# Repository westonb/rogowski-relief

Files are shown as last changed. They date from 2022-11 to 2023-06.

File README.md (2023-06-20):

# rogowski-relief
## An open source rogowski coil based current probe

This project is a rogowski coil based current probe designed to measure high frequency AC currents in tight spaces.
The sensing coil is optimized to be small enough to fit between the leads of a TO-220 transistor and can be slipped around the leads of many through hole power components for non-intrusive current measurements. 
The project consists of the rogowski coil and the integrator/amplifier which conditions the signal from the rogowski coil and provides an output voltage proportional to the current flowing in a conductor encircled by the rogowski coil. 

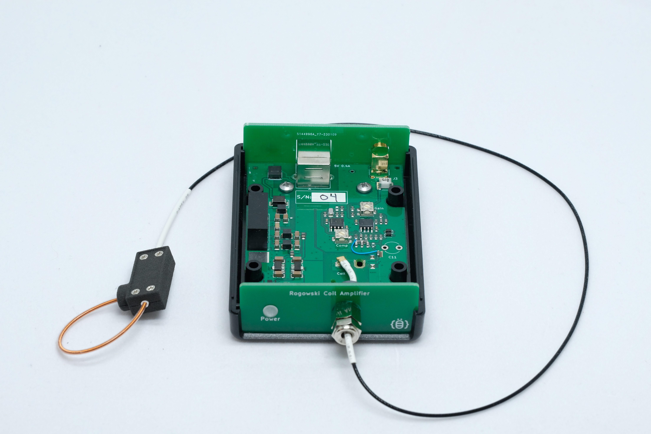
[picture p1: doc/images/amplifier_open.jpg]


## Operation
The sensing coil is open ended, with the free end held in place by a captive O-ring.
The enables the coil to be placed around a wire without breaking the circuit.
The amplifier provides a 0.1V/A output through a SMA connector and is designed to drive a 1M oscilloscope input through a coaxial cable. 
The amplifier is powered through a USB-B connector and draws less than 2W. 

## Specifications 

### Typical Electrical Performance

- **Bandwidth**: 800 Hz - 25 MHz
- **Sensitivity**: 0.1 Volts/Amp
- **Max Current**: +/- 30 A
- **Noise**: 6 mA RMS
- **Slew Rate**: 1 A/ns 

### Coil
- **OD**: < 1.7mm
- **Length**: 70mm

## Project Status
The current probe meets the original design goals and is suitable for general purpose lab use.
The most recently fabricated version of the integrator had some issues with interference from wireless signals (WiFi and LTE).
The PCB files in the latest commit have layout changes to fit the circuitry under a metal shielding can, which should largely remedy the issue.
There are only minor electrical revisions in the updated version, but it remains untested.

## Project Files

LTSpice simulation files for the time domain and frequency domain as well as noise simulation of the system are in the [sim](sim/) directory.
PCB design files and schematics are in the [PCB](pcb/) directory.
STL files of for the rogowski coil, mechanical BOM, and build instructions are in the [mech](mech/) directory.
Schematic of the integrator provided below for convenience. 

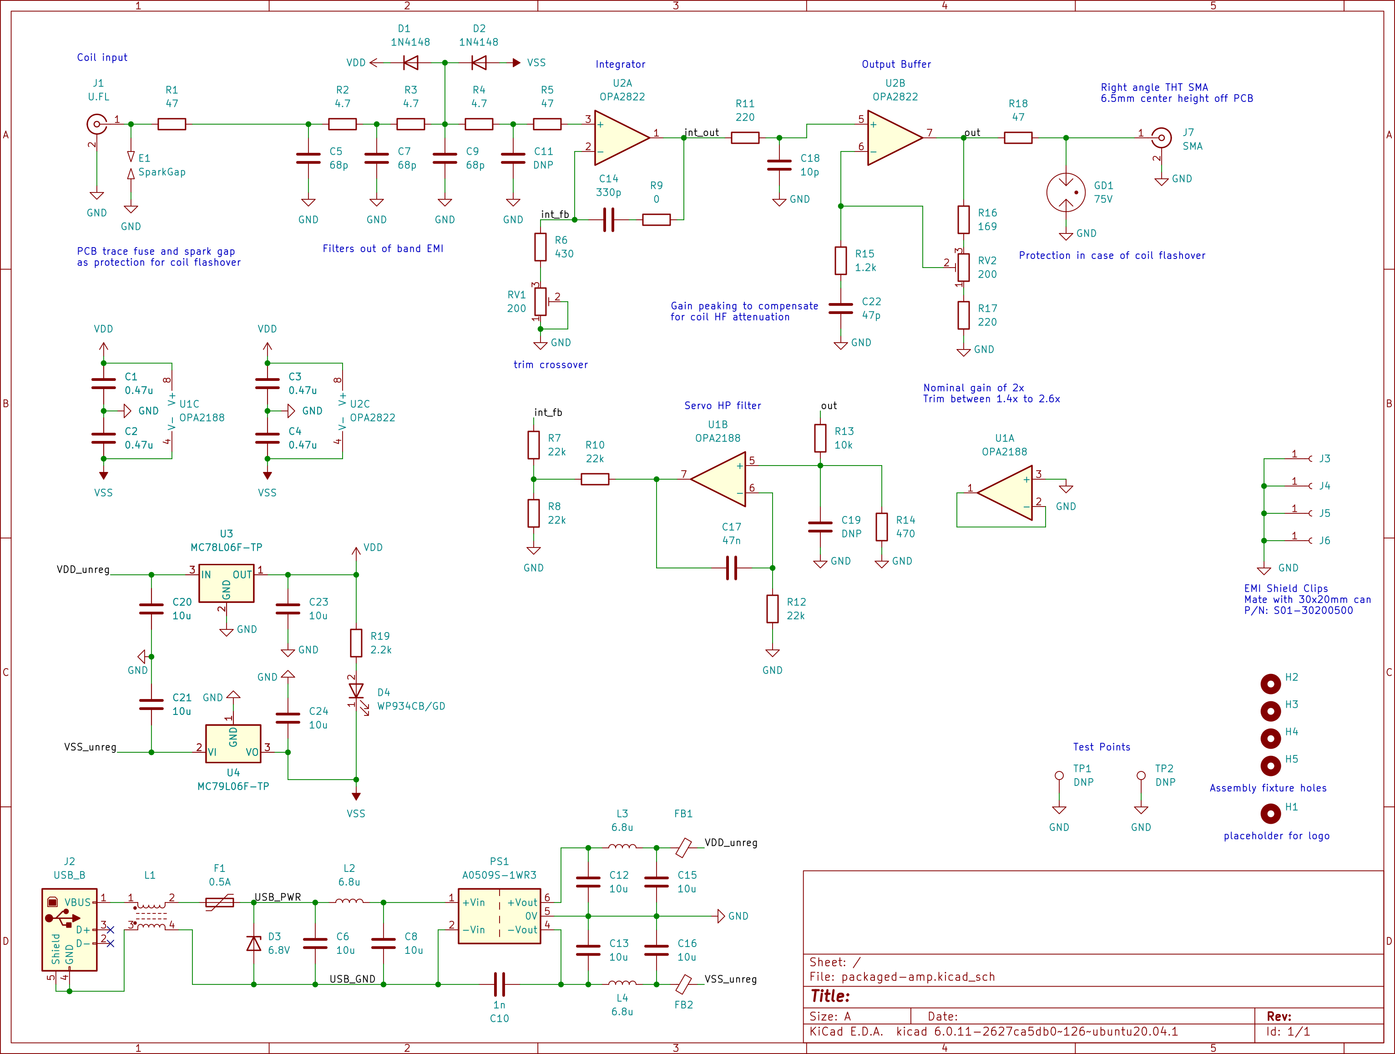
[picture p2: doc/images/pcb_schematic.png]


## Operating Principles 

### Rogowski Coil

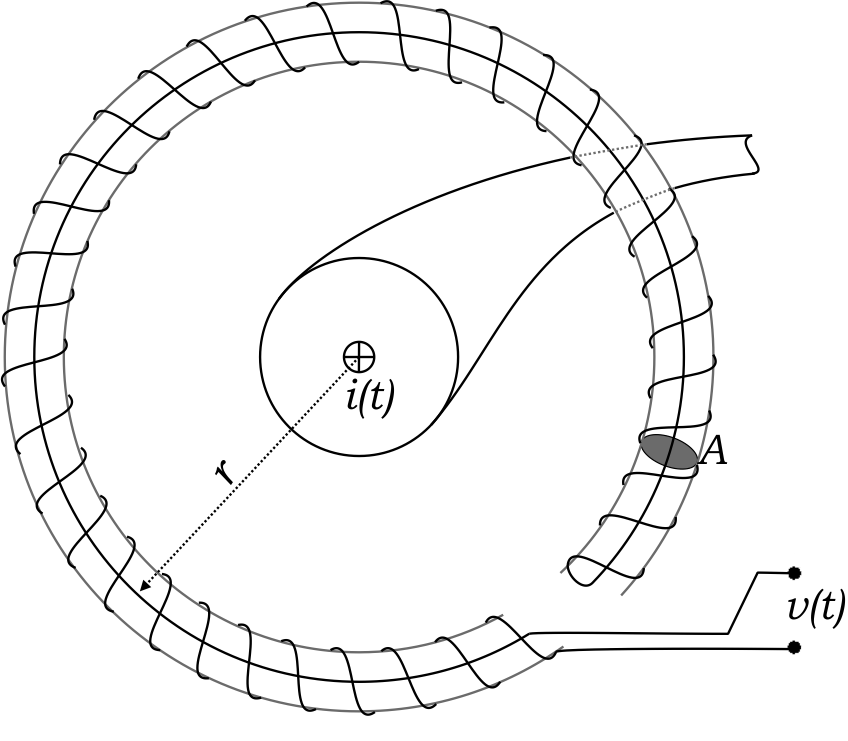
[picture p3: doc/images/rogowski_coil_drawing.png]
|  | 
|:--:| 
| *Rogowski Coil Drawing. Source: [Wikipedia](https://en.wikipedia.org/wiki/File:Rogowski_coil.png)* |

A rogowski coil is a toroidally wound air coil, consisting of many turns of wire wrapped around a coil form, with the start and end of the coil form joined together.
Each turn of the coil generates a voltage proportional to the change in the coupled magnetic field.
The sum of the voltage produced by all the turns is proportional to the change in the line integral of magnetic field around the path of the coil. 
As expressed by Ampere's law, the line integral of the magnetic field for any closed path is proportional to the current flowing in the enclosed area. 
Thus, the rogowski coil produces a voltage proportional to the change in current in a wire encircled by the coil with the output signal independent of the positioning of the wire. 
This allows for a flexible air-cored current sensor.
Unlike a current transformer, the rogowski coil generates a voltage proportional to the dI/dt and the signal must be integrated to produce an output proportional to current.
Additionally, as the dI/dt of a DC current is zero, the rogowski coil can not measure a DC current. 

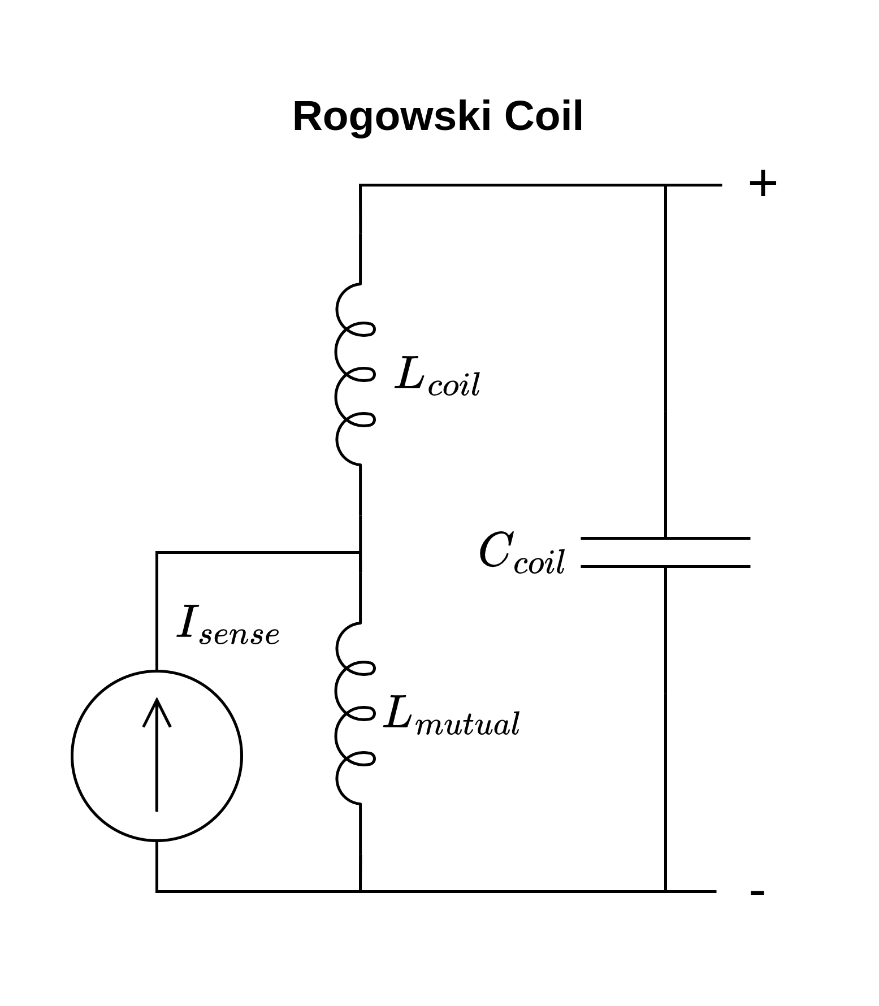
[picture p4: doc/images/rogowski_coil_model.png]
|  | 
|:--:| 
| *Circuit Model of Rogowski Coil* |

The rogowski coil can be modeled as a mutual inductance representing the flux coupling between the encircled wire and the coil, and the physical inductance and capacitance of the coil.
The induced signal can be modeled as a current source equal to that of the current in the encircled wire that is parallel with the mutual inductance.
The inductance and capacitance of the coil limit the maximum bandwidth and are dependent on the geometry of the coil.
The winding diameter and pitch determine the characteristic impedance of the coil, which determines the ratio of inductance to capacitance.
The bandwidth of the rogowski coil is maximized when the coil is terminated with a resistance equal to the characteristic impedance.
The total values of inductance and capacitance are determined by the length of the coil, which is proportional to the number of turns.

### Integrator
This project uses an op-amp based integrator to process the signal from the rogowski coil.
As integrator gain increases at low frequencies, the noise of the integrator ultimately limits the achievable low frequency bandwidth and is one of the most important design criteria.

This design uses an non-inverting integrator, best described in the paper [High Performance Rogowski Current Transducers](https://gmw.com/wp-content/uploads/2019/01/ias_2000_pem.pdf), and a servo high-pass filter with a second op-amp, best described in [A new filter topology for analog high-pass filters](https://www.ti.com/lit/an/slyt299/slyt299.pdf) to roll off the low frequency gain.

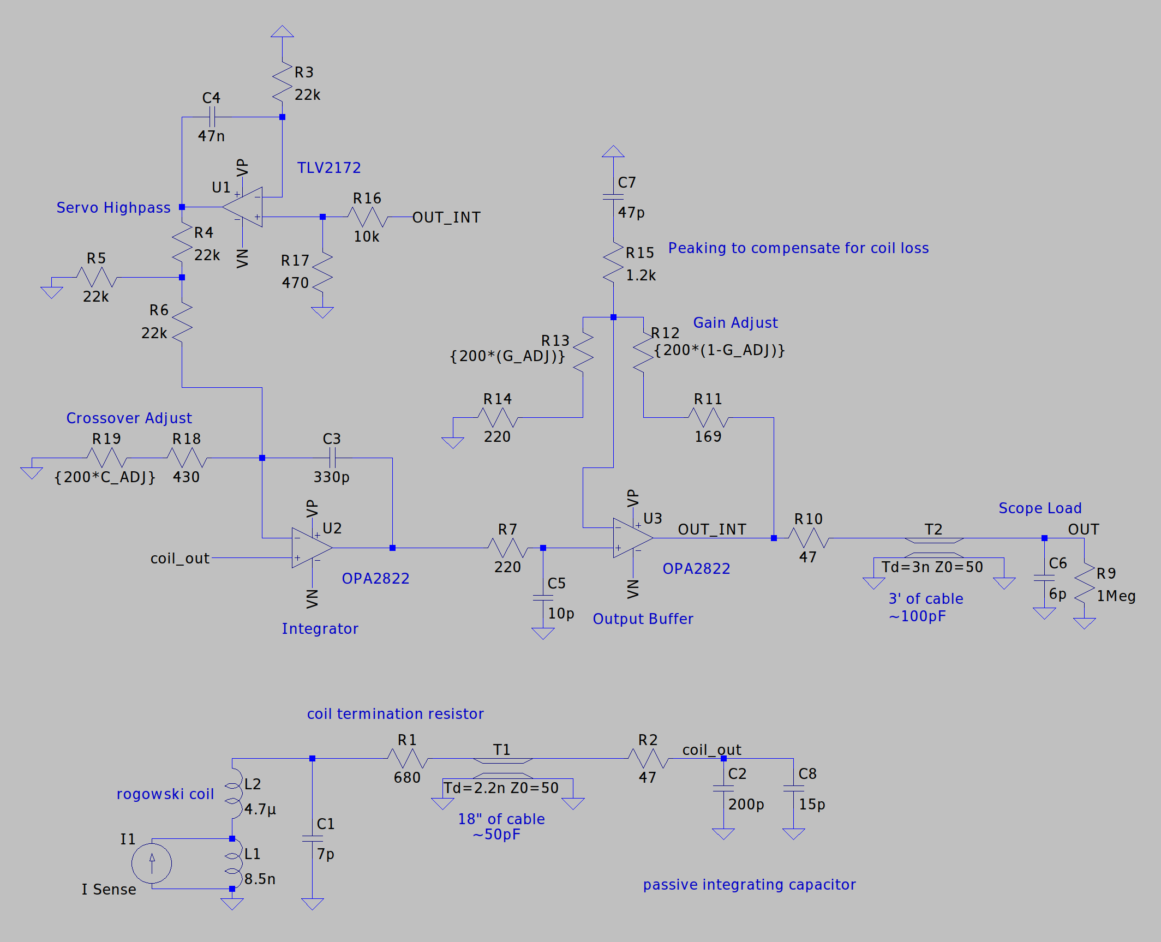
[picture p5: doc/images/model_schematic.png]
|  | 
|:--:| 
| *Annotated schematic of Rogowski coil and integrator* |

The non-inverting integrator consists of a passive RC integrator for high frequency integration and an op-amp integrator for low frequencies.
The passive RC integrator is comprised of the termination resistor for the rogowski coil, which matches the characteristic impedance of the rogowski coil and is co-located with the rogowski coil.
This allows for the capacitance of the cable between the rogowski coil and the integrator, which would otherwise limit bandwidth, to be incorporated as part of the integrator capacitance.
The non-inverting integrator requires that the crossover frequencies of the passive RC integrator and the op-amp match, necessitating a trimmer resistor.

The servo high-pass filter reduces the gain of the integrator below the cutoff frequency instead of leveling off the gain.
This reduces the noise of the system and nulls the DC offset of the amplifier, which could otherwise limit the output signal range.

An additional op-amp is used as an output buffer to provide adjustable gain to normalize the output to a fixed V/A ratio, and provide high frequency peaking to compensate for losses in the rogowski coil.

The op-amp used for the integrator was chosen for its low noise and high bandwidth.
Changing the op-amp can drastically change the output noise.

### Power Supply
The integrator is powered through a USB-B connector.
An isolated DC/DC converter module is uses to provide bipolar outputs of +/-9V which is then regulated down to +/-6V with linear regulators.
The linear regulators reduce switching noise which could otherwise couple into the output.
The isolated DC/DC converters are a commodity component that provide a bipolar output with lower cost and complexity than could be achieved with a solution using discrete components.
Additionally, the isolated module prevents any return current from passing through the output cable, which can inject noise or cause a DC offset.

## Safety 
No safety guarantees or warranty is implied for this design.
However, some safety precautions were taken as the rogowski coil could come into contact with conductors that are at a high voltage.
A PCB trace fuse on both connections from the coil is included on the PCB layout in the hope that the traces will blow and isolate the coil if the coil arcs over.
Additionally, a gas discharge tube is included on the output to further protect a connected device if such an arc-over would occur.

No voltage rating of the rogowski coil is implied or tested
The recommended heat-shrink has a wall thickness of 8 mil and a dielectric strength of 2kV/mil.
The recommended magnetic wire is MW 35-C rated and as such has a minimum dielectric strength of 2340V.
Mechanical wear and high dv/dt signals both adversely impact the voltage rating.

## Demo
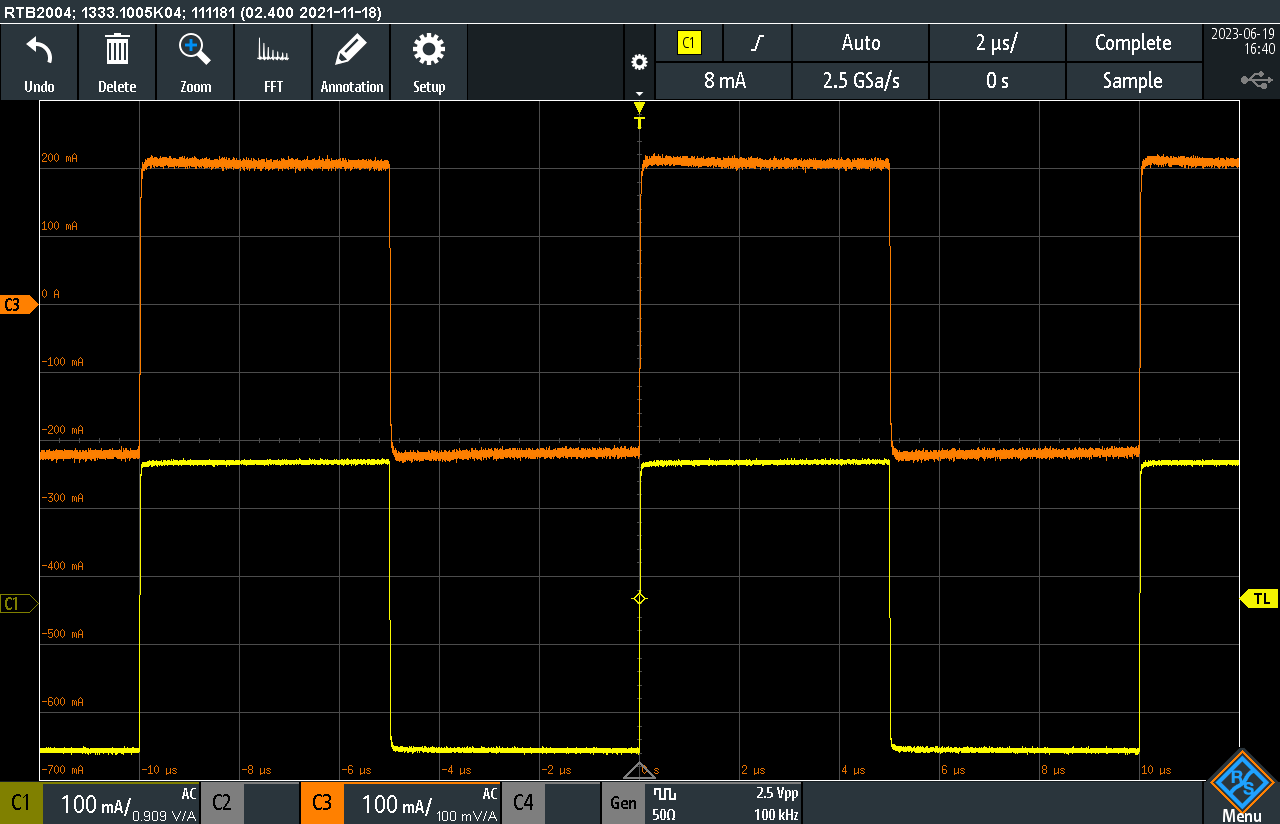
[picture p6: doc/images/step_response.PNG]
|  | 
|:--:| 
| *Probe step response. Reference (yellow) and probe output (orange)* |

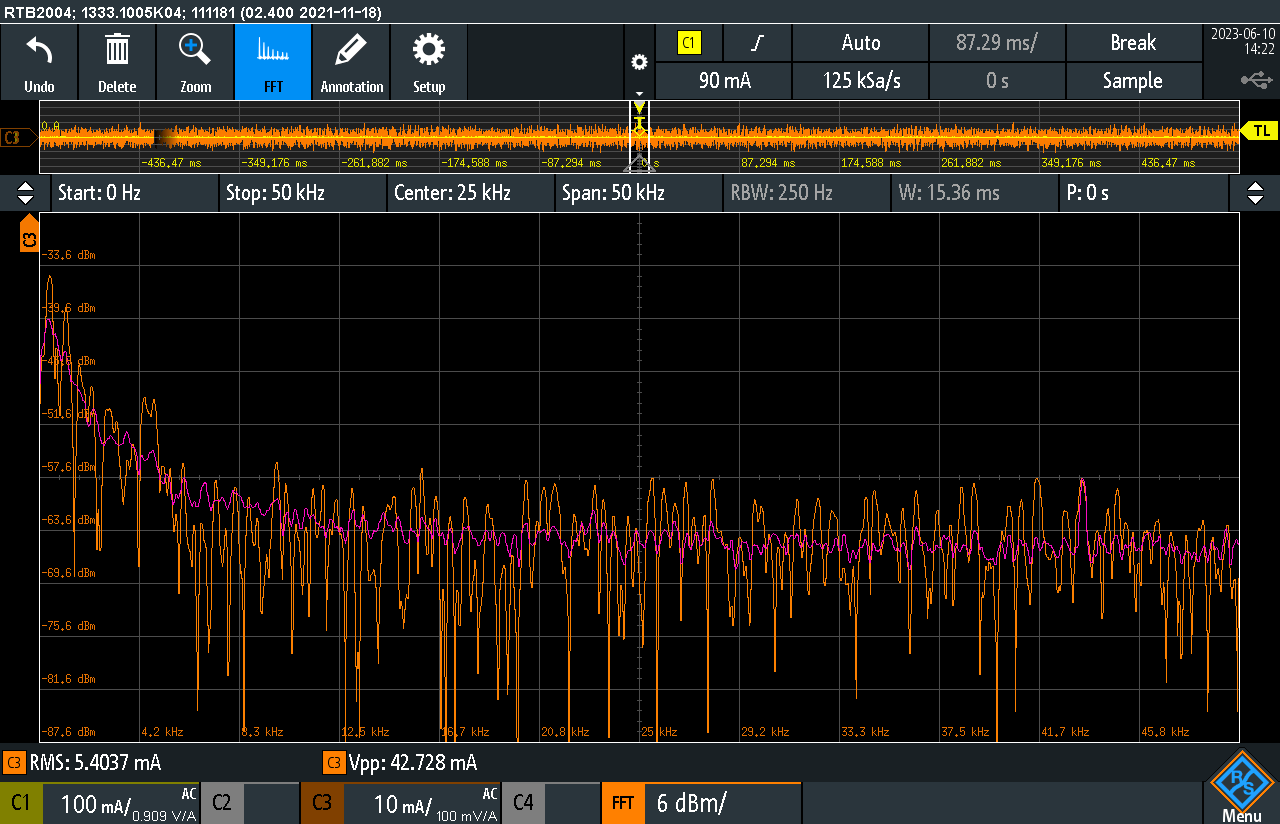
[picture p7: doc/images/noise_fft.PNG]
|  | 
|:--:| 
| *Output Noise and FFT* |

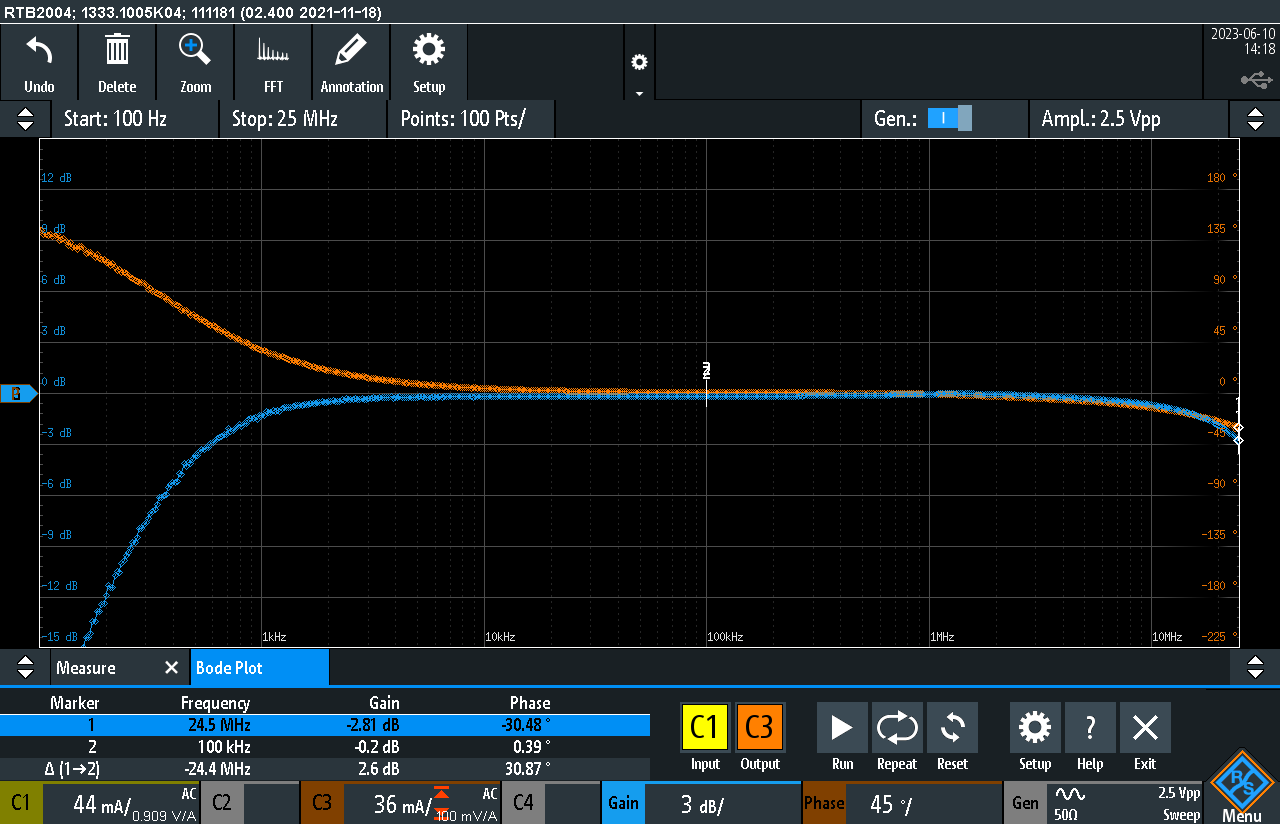
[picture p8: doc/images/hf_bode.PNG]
|  | 
|:--:| 
| *Probe frequency response* |

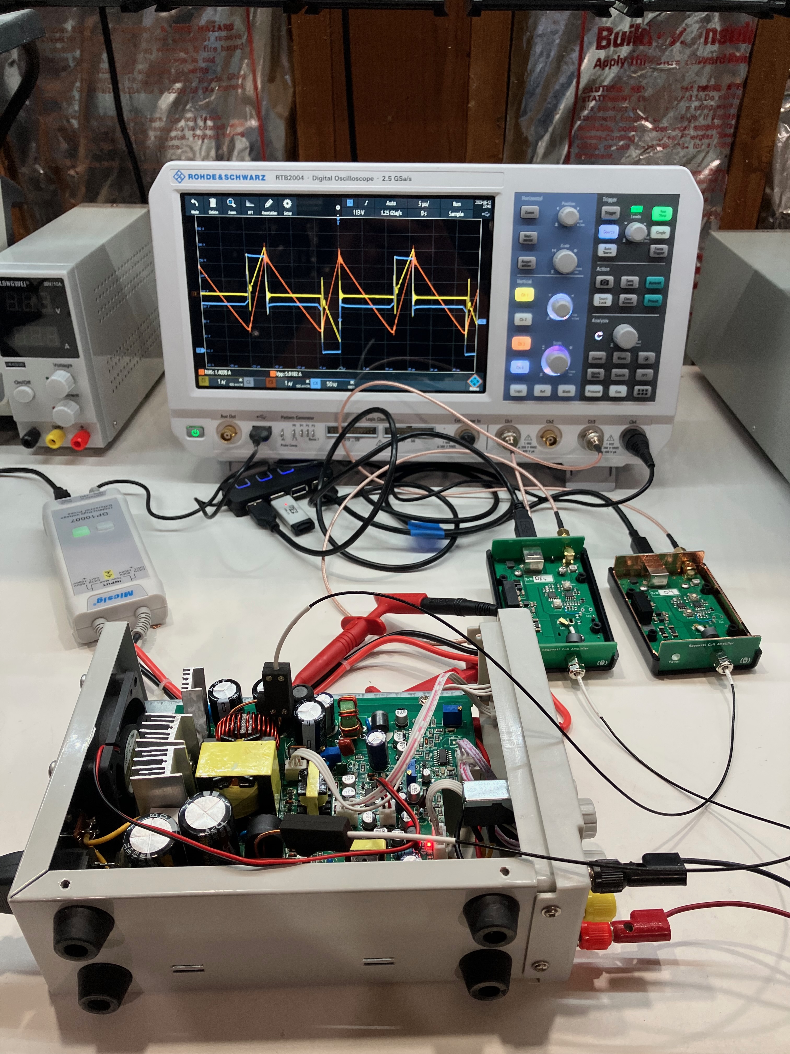
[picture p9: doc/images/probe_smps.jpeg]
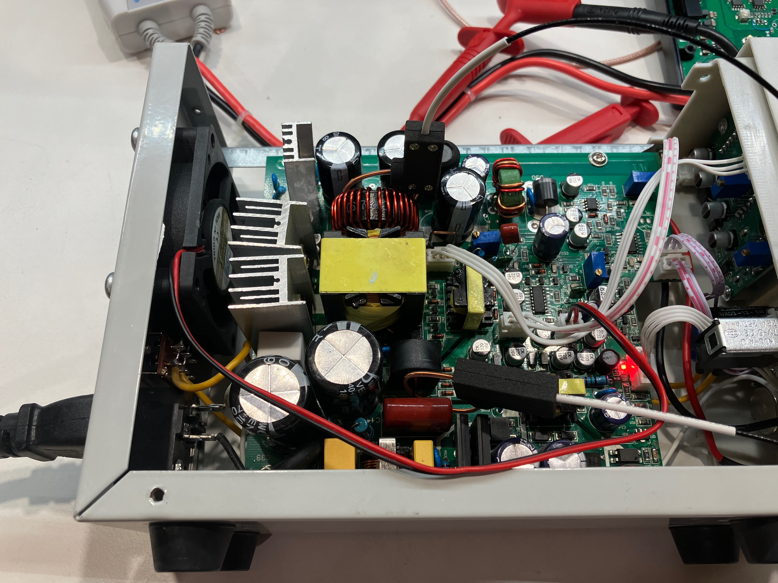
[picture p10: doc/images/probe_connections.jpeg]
|   | 
|:--:| 
| *Probing primary current (yellow) and output choke current (orange) of a SMPS* |

## Open Source
This work is licensed under a
[Creative Commons Attribution-ShareAlike 4.0 International License][cc-by-sa].

[][cc-by-sa]

[cc-by-sa]: http://creativecommons.org/licenses/by-sa/4.0/
[cc-by-sa-image]: https://licensebuttons.net/l/by-sa/4.0/88x31.png
[cc-by-sa-shield]: https://img.shields.io/badge/License-CC%20BY--SA%204.0-lightgrey.svg

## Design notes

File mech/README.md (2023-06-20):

# Build Instructions

## Rogowski Coil
The rogowski coil assembly consists of the wound coil, the 3D printed housing, and a small PCB which connects the rogowski coil to a U.FL connector and holds the termination resistor.

This rogowski coil design involved winding countless coils and trying over 20 types of heatshrink to find a design with good electrical performance, an outer diameter less than 1.7mm so the coil can fit between the leads of a TO-220 package, and is mechanically robust to bending and abrasion.
The integrator design is tuned to the properties of the rogowski coil described here.
If the coil size is changed or different materials are used the coil sensitivity will be different and the integrator may not be able to be adjusted for a nominal gain of 0.1V/A or a flat pulse response.

When winding the coil it is of utmost importance that the winding are uniform with no gaps or overlaps.
A constant winding tension is important as the tension causes shrinkage of the PTFE tube and a non-uniform cross section degrades the rejection of external magnetic fields.

As a general summary of the coil winding and assembly, the coil is wound on a PTFE tube.
The starting wire is secured by a small hole in the tube and passed through the center of the tube such that the start and end wires are at the same end.
UV cure epoxy is used to temporally secure the coil end after winding and the coil is protected with FEP heatshrink.
Additional heat shrink is used to strain relief the coil and and the coaxial cable that connects the rogowski coil to the integrator.

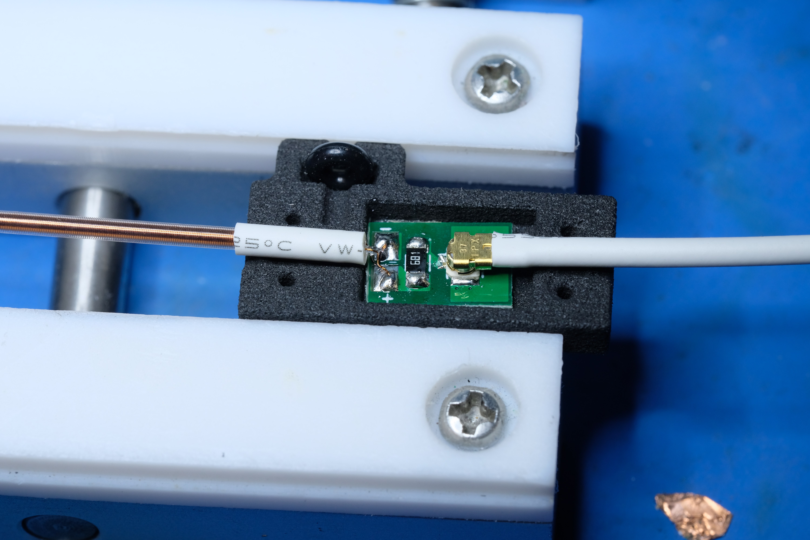
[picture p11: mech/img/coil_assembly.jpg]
|  | 
|:--:| 
| *Rogowski coil assembly before top case is installed* |

### 3D prints
1x of `coil_retainer_bottom.stl` and `coil_retainer_top.stl`
Printed in SLS nylon.
Test parts were printed out of 3201PA-F Nylon through JLCPCB.

### PCB
Coil terminator board populated with 680 ohm 1206 resistor and U.FL connector

### Parts
* 1.3x shrink ratio FEP for 18 Wire Gage, McMaster-Carr P/N 8703K114
* 2.5mm diameter 2x shrink ratio Polyolefin heat shrink, Digikey P/N HST-04-WT-4
* 0.6mm ID x 1mm OD PTFE tubing, [Amazon](https://www.amazon.com/gp/product/B07F5X51F5/)
* 36AWG MW 35-C magnet wire, Remington Industries P/N 36S200P
* 450mm 1.37mm coax cable, U.FL to U.FL, Digikey P/N 732-636201100450-ND
* 4x M1.6x6 flat head self tapping screw McMaster-Carr P/N 95893A162
* double sided adhesive tape, 3M 9495LE or similar
* UV cure epoxy, Loctite 3494 or similar
* 1/16"-004 O-Ring, McMaster-Carr P/N 9452K12

### Build Instructions

#### Bare Coil
1. Cut 1mm OD PTFE tube to 90mm length, cut hole big enough to pass 36 AWG wire 2mm from one end.
2. Thread 36 AWG magnet wire through the hole and have the wire exit the opposite end of the PFTE tube.
3. With the end of the magnet wire secured, wind a coil around the tube, winding should extend to the bottom 4mm of the tube. Use constant tension and ensure there are no gaps, overlaps, or kinks. This process can be easier by using a think stainless steel wire as a mandrel to hold the tube.
4. Secure the end of the winding with a small dab of UV cure epoxy. Cut the coil ends to 5mm length
5. Cut 100mm of the FEP heatshrink and heatshrink the coil with hot air at 250C. Start from the coil end and ensure the heat shrink starts flush with the PFET tube. After heating, trim the heatshink to be flush with the far end of the PTFE tube.
6. Cut 10mm of the Polyolefin heat shrink and apply to the wire end of the coil. Make sure that the heat shrink is flush with the existing heatshrink and coil end, it should not overhang. Process with 250C hot air. 
7. Strip the last 2mm of the wires of enamel and tin with solder.

#### Coil Assembly
1. Cut 50mm of the Polyolefin heat shrink and apply to both ends of the coax cable. The heat shrink should be flush with the neck of the U.FL connector. Process with 250C hot air.
2. Secure the coil terminator PCB to the inside of the bottom coil retainer housing with adhesive tape. The board edge should be flush with the wall where the rogowski coil is connected.
3. Solder the rogowski coil leads to the pads on the coil terminator board. Minimize any exposed loops. 
4. Connect the coaxial cable to the U.FL connector on the coil terminator board.
5. Place an O-ring in the O-ring retaining grove.
6. Make sure that the end of the rogowski coil is flush with the inner wall. Cover with the top coil retainer housing, compress the housing halves together and secure with M1.6x6 self tapping screws. Use gentle tightening force to ensure screw holes do not strip out. 

## Integrator 
The final assembly is the integrator PCBA and the rogowski coil.
The project is contained in an off the shelf project box and uses PCB based front and rear panels.
The integrator PCBA was optimized for assembly with the JLCPCB PCBA service, but component availability varies.
The KiCad project contains both a BOM with LCSC part numbers and a BOM with western part numbers stocked at Digikey. 

|  | 
|:--:| 
| *Complete current probe with top case open* |

### PCBs
* Integrator PCBA
* Front panel PCB
* Rear Panel PCB

### Parts

* \#4-1/4" thread cutting screws, McMaster-Carr P/N 94629A150
* M6X1.0 Cable gland, Generic, [Aliexpress example](https://www.aliexpress.us/item/3256803804996455.html)
* M6X1.0 thin hex nut, McMaster-Carr P/N 90710A038
* ABS Project Enclosure, Digikey P/N 377-1651-ND
* Ferrite EMI suppression bead, Digikey P/N 1934-1323-ND
* 5mm LED light pipe, Digikey P/N 492-1531-ND

#### Assembly
1. Attach the M6 cable gland to the front panel PCB with the M6 nut and tighten. Press fit the LED light pipe into the front panel.
2. Slide the rear panel over the SMA and USB connectors of the integrator PCB and slide the integrator PCBA and panel PCBs into the project box.
3. Secure integrator PCBA to the project box with the \#4-1/4" screws.
4. Thread the coaxial cable of the rogowski coil assembly through the cable gland. 
5. Slide the ferrite bead over the side of the coaxial cable that is inside the project box.
6. Connect the U.FL connector of the rogowski coil assembly to the U.FL connector of the integrator PCBA. Adjust the cable length such that the cable is not under tension and then tighten the cable gland.
7. Secure the ferrite bead to the integrator PCBA with adhesive or zip-tie. 
8. After calibration, install the top of the project box. 

#### Calibration
With a 100KHz square wave current source adjust the gain and compensation trimmer resistors such that the pulse response is flat and the probe gain is the nominal 0.1V/A.
The compensation trimmer adjusts the rising edge of the waveform and also impacts the gain and should be adjusted first.

A function generator driving a 10 turn coil and a 1 ohm shunt resistor to provide a reference signal should provide a sufficient signal for calibration.
When multiple loops of the same wire pass through the sensing coil the measured current is the current flowing through the wire times the number of turns.

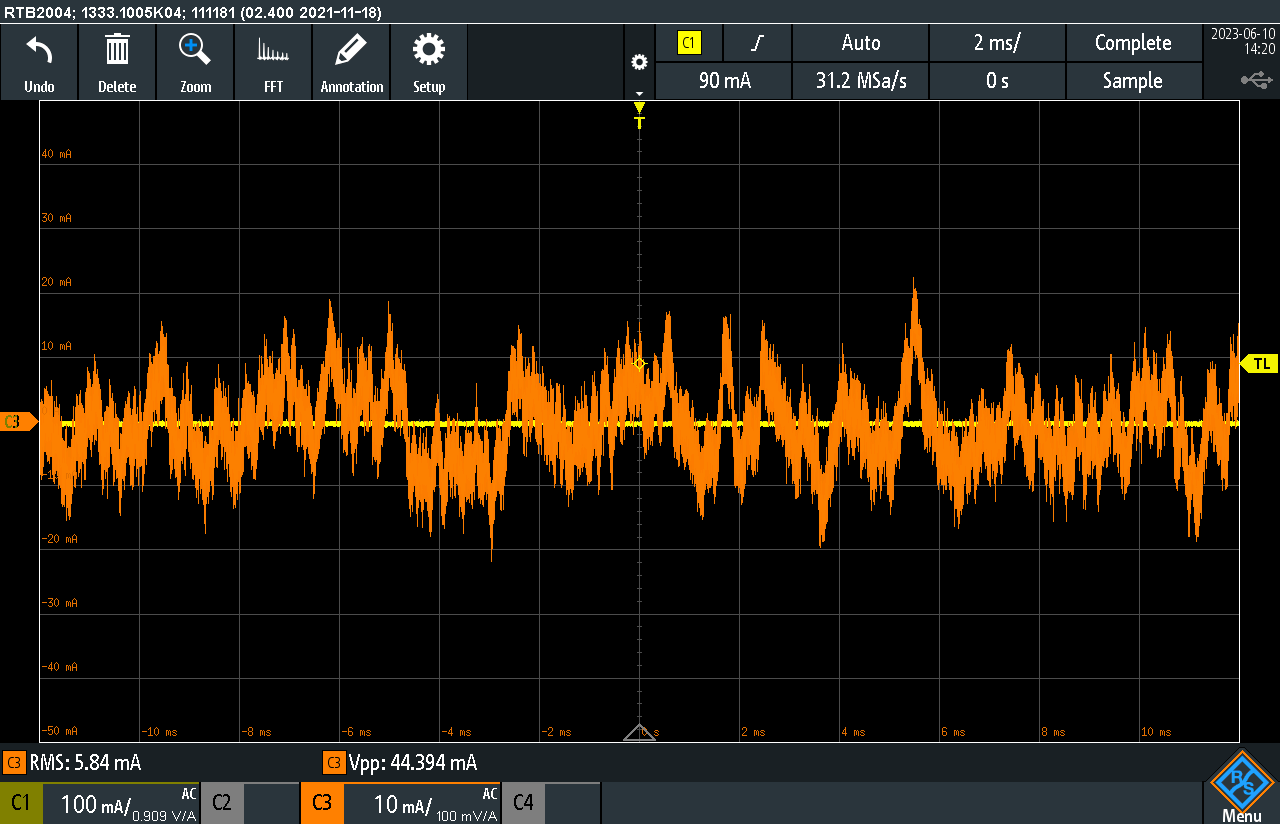
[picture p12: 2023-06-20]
doc/images/noise.PNG

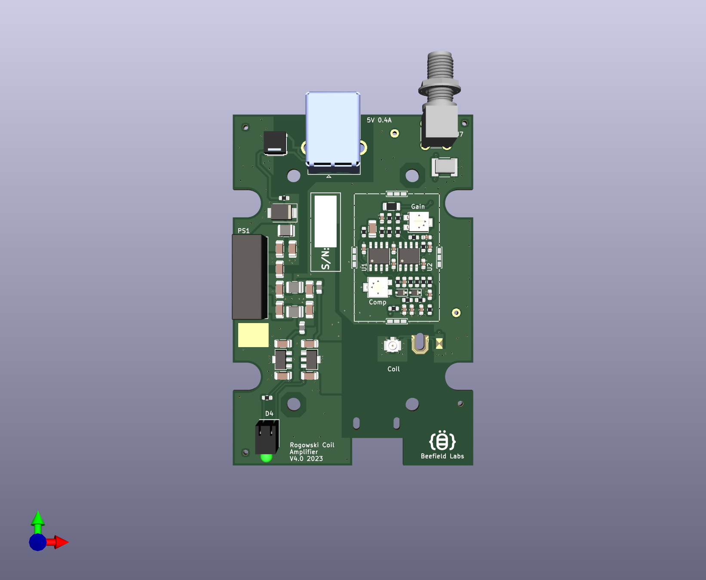
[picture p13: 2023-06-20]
doc/images/pcb_render.png

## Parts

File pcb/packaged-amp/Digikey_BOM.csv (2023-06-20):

Ref | Qty | Value | Footprint | Description | MPN
C1, C2, C3, C4, | 4 | 0.47u | Capacitor_SMD:C_0603_1608Metric | Unpolarized capacitor | CL10B474KA8NNNC
C5, C7, C9, | 3 | 68p | Capacitor_SMD:C_0603_1608Metric | Unpolarized capacitor | CL10C680JB8NNNC
C6, C8, C12, C13, C15, C16, C20, C21, C23, C24, | 10 | 10u | Capacitor_SMD:C_1206_3216Metric | Unpolarized capacitor | CL31A106KBHNNNE
C10, | 1 | 1n | Capacitor_SMD:C_1206_3216Metric | Unpolarized capacitor | 1206B102K202NT
C11, C19, | 2 | DNP | Capacitor_SMD:C_0603_1608Metric | Unpolarized capacitor
C14, | 1 | 330p | Capacitor_SMD:C_0603_1608Metric | Unpolarized capacitor | CL10C331JB8NNNC
C17, | 1 | 47n | Capacitor_SMD:C_1206_3216Metric | Unpolarized capacitor | GRM31M5C1H473JA01L
C18, | 1 | 10p | Capacitor_SMD:C_0603_1608Metric | Unpolarized capacitor | CL10C100JB8NNNC
C22, | 1 | 47p | Capacitor_SMD:C_0603_1608Metric | Unpolarized capacitor | CL10C470JB8NNNC
D1, D2, | 2 | 1N4148 | Diode_SMD:D_SOD-323F | Diode | 1N4148WS RRG
D3, | 1 | 6.8V | Diode_SMD:D_SMB | Zener diode | P6SMB6.8CA/TR13
D4, | 1 | WP934CB/GD | wbraun_smd:LED-T1-RIGHT-ANGLE_4.6x4.4mm | Light emitting diode | WP934CB/GD
E1, | 1 | SparkGap | wbraun_smd:Spark_Gap | Spark gap
F1, | 1 | 0.5A | Fuse:Fuse_0603_1608Metric | Resettable fuse, polymeric positive temperature coefficient | 0467.750NRHF
FB1, FB2, | 2 | FerriteBead_Small | Inductor_SMD:L_0805_2012Metric | Ferrite bead, small symbol | 742792040
GD1, | 1 | 75V | wbraun_smd:GDT_1812 | Gas Discharge Tube with 2 Pins | 4532-075-LF
H1, | 1 | MountingHole | wbraun_smd:beefield_logo_small | Mounting Hole without connection
H2, H3, H4, H5, | 4 | MountingHole | wbraun_smd:JLC_TOOLING_HOLE | Mounting Hole without connection
J1, | 1 | U.FL | Connector_Coaxial:U.FL_Hirose_U.FL-R-SMT-1_Vertical | coaxial connector (BNC, SMA, SMB, SMC, Cinch/RCA, LEMO, ...) | U.FL-R-SMT-1(10)
J2, | 1 | USB_B | wbraun_smd:USB_B_OST_USB-B1HSxx_Horizontal | USB Type B connector | USB-B1HSB6
J3, J4, J5, J6, | 4 | Conn_01x01_Female | wbraun_smd:CLIP_ECT81800C036 | Generic connector, single row, 01x01, script generated (kicad-library-utils/schlib/autogen/connector/) | S1001-46R
J7, | 1 | SMA | wbraun_smd:SMA_Molex_73251-2200_Horizontal | coaxial connector (BNC, SMA, SMB, SMC, Cinch/RCA, LEMO, ...) | RF2-49B-T-00-50-G-HDW
L1, | 1 | DLW5BTM142SQ2L | wbraun_smd:L_CommonModeChoke_Murata_DLW5BTM | Coupled inductor with ferrite core | DLW5BTM142SQ2L
L2, L3, L4, | 3 | 6.8u | Inductor_SMD:L_1210_3225Metric | Inductor | NLCV32T-6R8M-EF
PS1, | 1 | A0509S-1WR3 | Converter_DCDC:Converter_DCDC_XP_POWER-IHxxxxS_THT | XP Power 2W, 1000 VDC Isolated DC/DC Converter Module, Dual Output Voltage ±3.3V, ±200mA, 5V Input Voltage, SIP | A0509S-1WR3
R1, R5, | 2 | 47 | Resistor_SMD:R_0603_1608Metric | Resistor | RC0603FR-0747RL
R2, R3, R4, | 3 | 4.7 | Resistor_SMD:R_0603_1608Metric | Resistor | RC0603JR-074R7L
R6, | 1 | 430 | Resistor_SMD:R_0603_1608Metric | Resistor | RC0603FR-07430RL
R7, R8, R10, R12, | 4 | 22k | Resistor_SMD:R_0603_1608Metric | Resistor | RMCF0603FG22K0
R9, | 1 | 0 | Resistor_SMD:R_0603_1608Metric | Resistor | ERJ-3GEY0R00V
R11, R17, | 2 | 220 | Resistor_SMD:R_0603_1608Metric | Resistor | RC0603FR-07220RL
R13, | 1 | 10k | Resistor_SMD:R_0603_1608Metric | Resistor | RC0603FR-0710KL
R14, | 1 | 470 | Resistor_SMD:R_0603_1608Metric | Resistor | RC0603FR-07470RL
R15, | 1 | 1.2k | Resistor_SMD:R_0603_1608Metric | Resistor | RC0603FR-071K2L
R16, | 1 | 169 | Resistor_SMD:R_0603_1608Metric | Resistor | RC0603FR-07169RL
R18, | 1 | 47 | Resistor_SMD:R_1206_3216Metric | Resistor
R19, | 1 | 2.2k | Resistor_SMD:R_0603_1608Metric | Resistor | RC0603FR-072K2L
RV1, RV2, | 2 | 200 | Potentiometer_SMD:Potentiometer_Bourns_3314G_Vertical | Trim-potentiometer | 3314G-1-201E
TP1, TP2, | 2 | DNP | wbraun_smd:THM_MINI | test point
U1, | 1 | OPA2188 | Package_SO:SOIC-8_3.9x4.9mm_P1.27mm | Dual SoundPlus High Performance, Bipolar-Input Audio Operational Amplifiers, SOIC-8/MSOP-8 | OPA2188AIDR
U2, | 1 | OPA2822 | Package_SO:SOIC-8_3.9x4.9mm_P1.27mm | Dual SoundPlus High Performance, Bipolar-Input Audio Operational Amplifiers, SOIC-8/MSOP-8 | OPA2822U
U3, | 1 | MC78L06F-TP | Package_TO_SOT_SMD:SOT-89-3 | Positive 100mA 30V Linear Regulator, Fixed Output 6V, SOT-89 | MC78L06F-TP
U4, | 1 | MC79L06F-TP | Package_TO_SOT_SMD:SOT-89-3 | Negative 100mA -30V Linear Regulator, Fixed Output -5V, SOT-89 | MC79L06F-TP

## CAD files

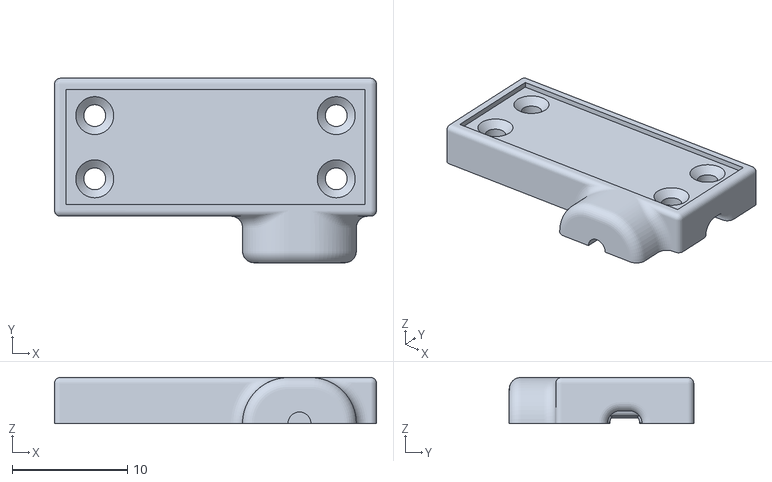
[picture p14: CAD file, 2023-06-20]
mech/coil_retainer_top.stl
28.0 x 16.1 x 4.00

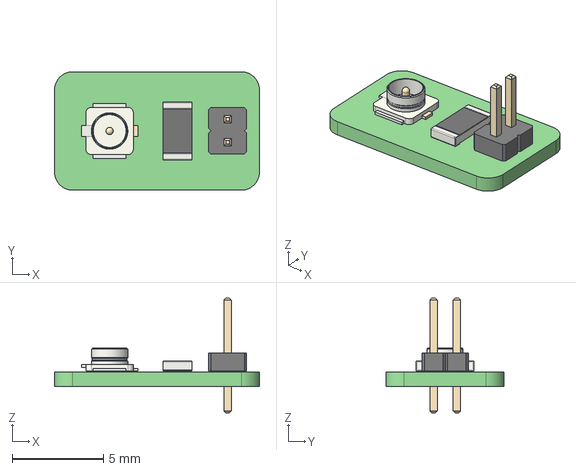
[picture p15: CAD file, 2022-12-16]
pcb/coil_terminator/coil_terminator.step
11.2 x 6.50 x 6.30 mm
coil_terminator PCB

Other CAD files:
mech/coil_retainer_bottom.stl

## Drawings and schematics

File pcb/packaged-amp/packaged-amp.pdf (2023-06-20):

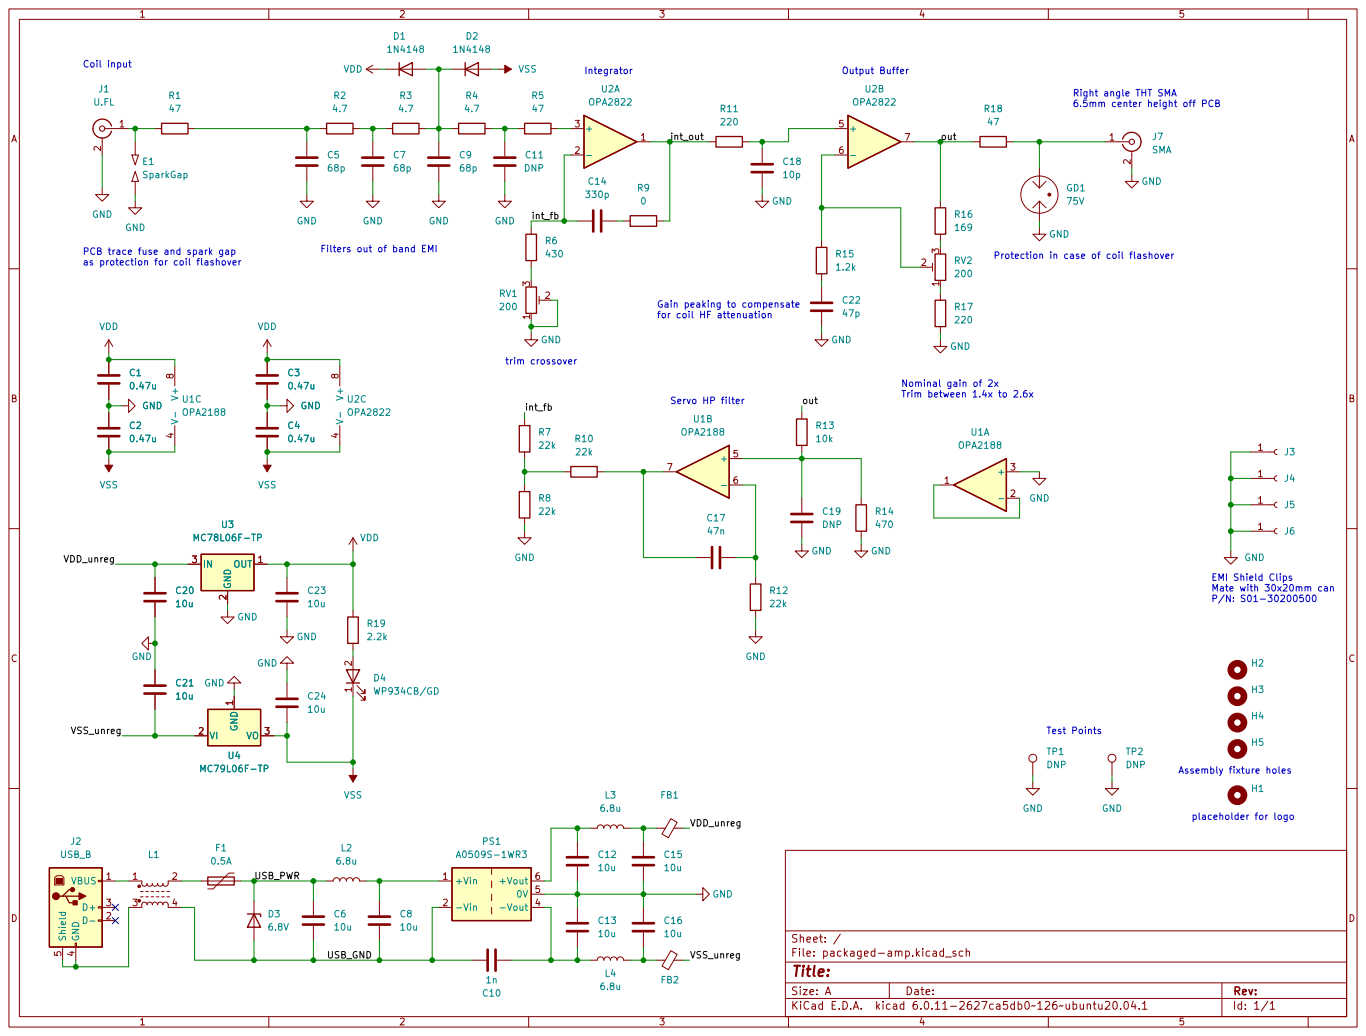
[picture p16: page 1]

6.5mm center height off PCB

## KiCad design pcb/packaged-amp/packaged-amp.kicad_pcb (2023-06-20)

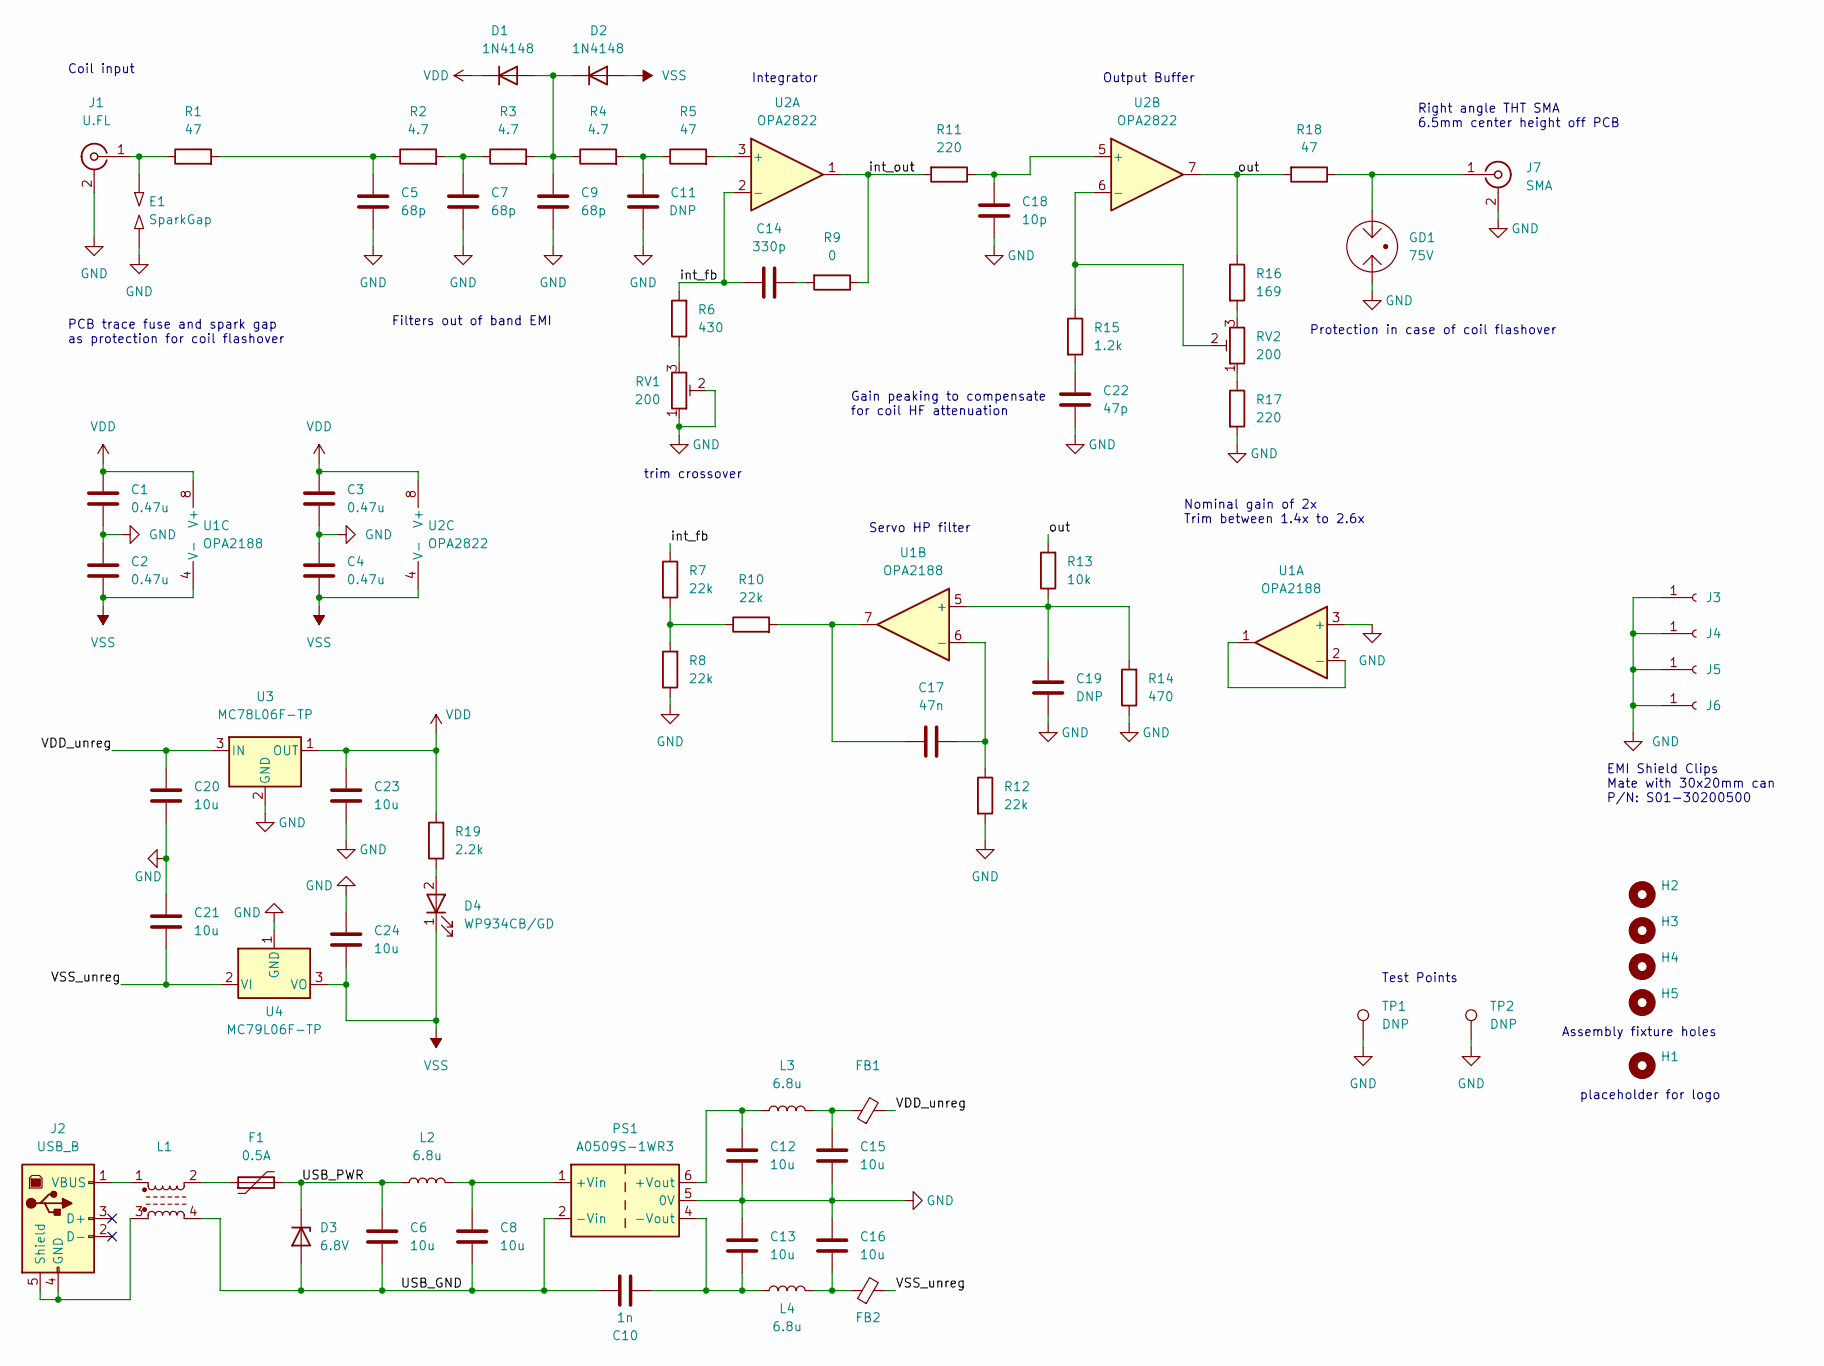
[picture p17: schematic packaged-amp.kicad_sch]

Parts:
C1, C2, C3, C4: 0.47u; C_0603_1608Metric; MPN CL10B474KA8NNNC; JLC_MPN C1623
C5, C7, C9: 68p; C_0603_1608Metric; MPN CL10C680JB8NNNC; JLC_MPN C28262
C6, C8, C12, C13, C15, C16, C20, C21, C23, C24: 10u; C_1206_3216Metric; MPN CL31A106KBHNNNE; JLC_MPN C13585
C10: 1n; C_1206_3216Metric; MPN 1206B102K202NT; JLC_MPN C9196
C11, C19: DNP; C_0603_1608Metric
C14: 330p; C_0603_1608Metric; MPN CL10C331JB8NNNC; JLC_MPN C1664
C17: 47n; C_1206_3216Metric; MPN GRM31M5C1H473JA01L; JLC_MPN C21812
C18: 10p; C_0603_1608Metric; MPN CL10C100JB8NNNC; JLC_MPN C1634
C22: 47p; C_0603_1608Metric; MPN CL10C470JB8NNNC; JLC_MPN C1671
D1, D2: 1N4148; D_SOD-323F; MPN 1N4148WS RRG; JLC_MPN C2128
D3: 6.8V; D_SMB; MPN P6SMB6.8CA/TR13; JLC_MPN C78395
D4: WP934CB/GD; LED-T1-RIGHT-ANGLE_4.6x4.4mm; MPN WP934CB/GD; JLC_MPN C2929607
E1: SparkGap; Spark_Gap
F1: 0.5A; Fuse_0603_1608Metric; MPN 0467.750NRHF; JLC_MPN C206991
FB1, FB2: FerriteBead_Small; L_0805_2012Metric; MPN 742792040; JLC_MPN C1015
GD1: 75V; GDT_1812; MPN 4532-075-LF; JLC_MPN C522627
H1: MountingHole; beefield_logo_small
H2, H3, H4, H5: MountingHole; JLC_TOOLING_HOLE
J1: U.FL; U.FL_Hirose_U.FL-R-SMT-1_Vertical; MPN U.FL-R-SMT-1(10); JLC_MPN C88373
J2: USB_B; USB_B_OST_USB-B1HSxx_Horizontal; MPN USB-B1HSB6; JLC_MPN C498173
J3, J4, J5, J6: Conn_01x01_Female; CLIP_ECT81800C036; MPN S1001-46R; JLC_MPN C5446941
J7: SMA; SMA_Molex_73251-2200_Horizontal; MPN RF2-49B-T-00-50-G-HDW; JLC_MPN C1509208
L1: DLW5BTM142SQ2L; L_CommonModeChoke_Murata_DLW5BTM; MPN DLW5BTM142SQ2L; JLC_MPN C91596
L2, L3, L4: 6.8u; L_1210_3225Metric; MPN NLCV32T-6R8M-EF; JLC_MPN C250230
PS1: A0509S-1WR3; Converter_DCDC_XP_POWER-IHxxxxS_THT; MPN A0509S-1WR3; JLC_MPN C131900
R1, R5: 47; R_0603_1608Metric; MPN RC0603FR-0747RL; JLC_MPN C23182
R2, R3, R4: 4.7; R_0603_1608Metric; MPN RC0603JR-074R7L; JLC_MPN C23164
R6: 430; R_0603_1608Metric; MPN RC0603FR-07430RL; JLC_MPN C23170
R7, R8, R10, R12: 22k; R_0603_1608Metric; MPN RMCF0603FG22K0; JLC_MPN C31850
R9: 0; R_0603_1608Metric; MPN ERJ-3GEY0R00V; JLC_MPN C21189
R11, R17: 220; R_0603_1608Metric; MPN RC0603FR-07220RL; JLC_MPN C22962
R13: 10k; R_0603_1608Metric; MPN RC0603FR-0710KL; JLC_MPN C25804
R14: 470; R_0603_1608Metric; MPN RC0603FR-07470RL; JLC_MPN C23179
R15: 1.2k; R_0603_1608Metric; MPN RC0603FR-071K2L; JLC_MPN C22765
R16: 169; R_0603_1608Metric; MPN RC0603FR-07169RL; JLC_MPN C22889
R18: 47; R_1206_3216Metric; JLC_MPN C17969
R19: 2.2k; R_0603_1608Metric; MPN RC0603FR-072K2L; JLC_MPN C4190
RV1, RV2: 200; Potentiometer_Bourns_3314G_Vertical; MPN 3314G-1-201E; JLC_MPN C52238
TP1, TP2: DNP; THM_MINI
U1: OPA2188; SOIC-8_3.9x4.9mm_P1.27mm; MPN OPA2188AIDR; JLC_MPN C17271
U2: OPA2822; SOIC-8_3.9x4.9mm_P1.27mm; MPN OPA2822U; JLC_MPN C2059808
U3: MC78L06F-TP; SOT-89-3; MPN MC78L06F-TP; JLC_MPN C81358
U4: MC79L06F-TP; SOT-89-3; MPN MC79L06F-TP; JLC_MPN C8619

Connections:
/USB_GND: C6.2, C8.2, C10.1, D3.2 (A), L1.4, PS1.2 (-Vin)
/USB_PWR: C6.1, D3.1 (K), F1.2, L2.1
/VDD_unreg: C20.1, FB1.2, U3.3 (IN)
/VSS_unreg: C21.2, FB2.2, U4.2 (VI)
/int_fb: C14.1, R6.2, R7.1, U2.2 (-)
/int_out: R9.1, R11.2, U2.1
/out: R13.2, R16.1, R18.2, U2.7
GND: C1.2, C2.1, C3.2, C4.1, C5.2, C7.2, C9.2, C11.1, C12.2, C13.1, C15.2, C16.1, C18.2, C19.1, C20.2, C21.1, C22.2, C23.2, C24.1, E1.1, GD1.2, J1.2 (Ext), J3.1, J4.1, J5.1, J6.1, J7.2 (Ext), PS1.5 (0V), R8.1, R12.2, R14.1, R17.2, RV1.1, RV1.2, TP1.1, TP2.1, U1.3 (+), U3.2 (GND), U4.1 (GND)
unnamed: C5.1, R1.2, R2.1
unnamed: C8.1, L2.2, PS1.1 (+Vin)
unnamed: C14.2, R9.2
unnamed: C17.1, R10.2, U1.7
unnamed: C17.2, R12.1, U1.6 (-)
unnamed: C19.2, R13.1, R14.2, U1.5 (+)
unnamed: D4.2 (A), R19.1
unnamed: E1.2, J1.1 (In), R1.1
unnamed: C15.1, FB1.1, L3.2
unnamed: C16.2, FB2.1, L4.2
unnamed: GD1.1, J7.1 (In), R18.1
unnamed: J2.1 (VBUS), L1.1
unnamed: J2.4 (GND), J2.5 (Shield), L1.3
unnamed: F1.1, L1.2
unnamed: C10.2, C13.2, L4.1, PS1.4 (-Vout)
unnamed: C12.1, L3.1, PS1.6 (+Vout)
unnamed: C7.1, R2.2, R3.1
unnamed: C9.1, D1.2 (A), D2.1 (K), R3.2, R4.1
unnamed: C11.2, R4.2, R5.1
unnamed: R6.1, RV1.3
unnamed: R7.2, R8.2, R10.1
unnamed: C18.1, R11.1, U2.5 (+)
unnamed: C22.1, R15.2
unnamed: R16.2, RV2.3
unnamed: R17.1, RV2.1
unnamed: U1.1, U1.2 (-)
unnamed: R5.2, U2.3 (+)
unnamed: R15.1, RV2.2, U2.6 (-)
VDD: C1.1, C3.1, C23.1, D1.1 (K), R19.2, U1.8 (V+), U2.8 (V+), U3.1 (OUT)
VSS: C2.2, C4.2, C24.2, D2.2 (A), D4.1 (K), U1.4 (V-), U2.4 (V-), U4.3 (VO)

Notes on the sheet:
Coil input
Gain peaking to compensate for coil HF attenuation
Servo HP filter
Integrator
PCB trace fuse and spark gap as protection for coil flashover
Test Points
Output Buffer
Protection in case of coil flashover
Right angle THT SMA 6.5mm center height off PCB
Filters out of band EMI
Assembly fixture holes
placeholder for logo
EMI Shield Clips Mate with 30x20mm can P/N: S01-30200500
Nominal gain of 2x Trim between 1.4x to 2.6x
trim crossover

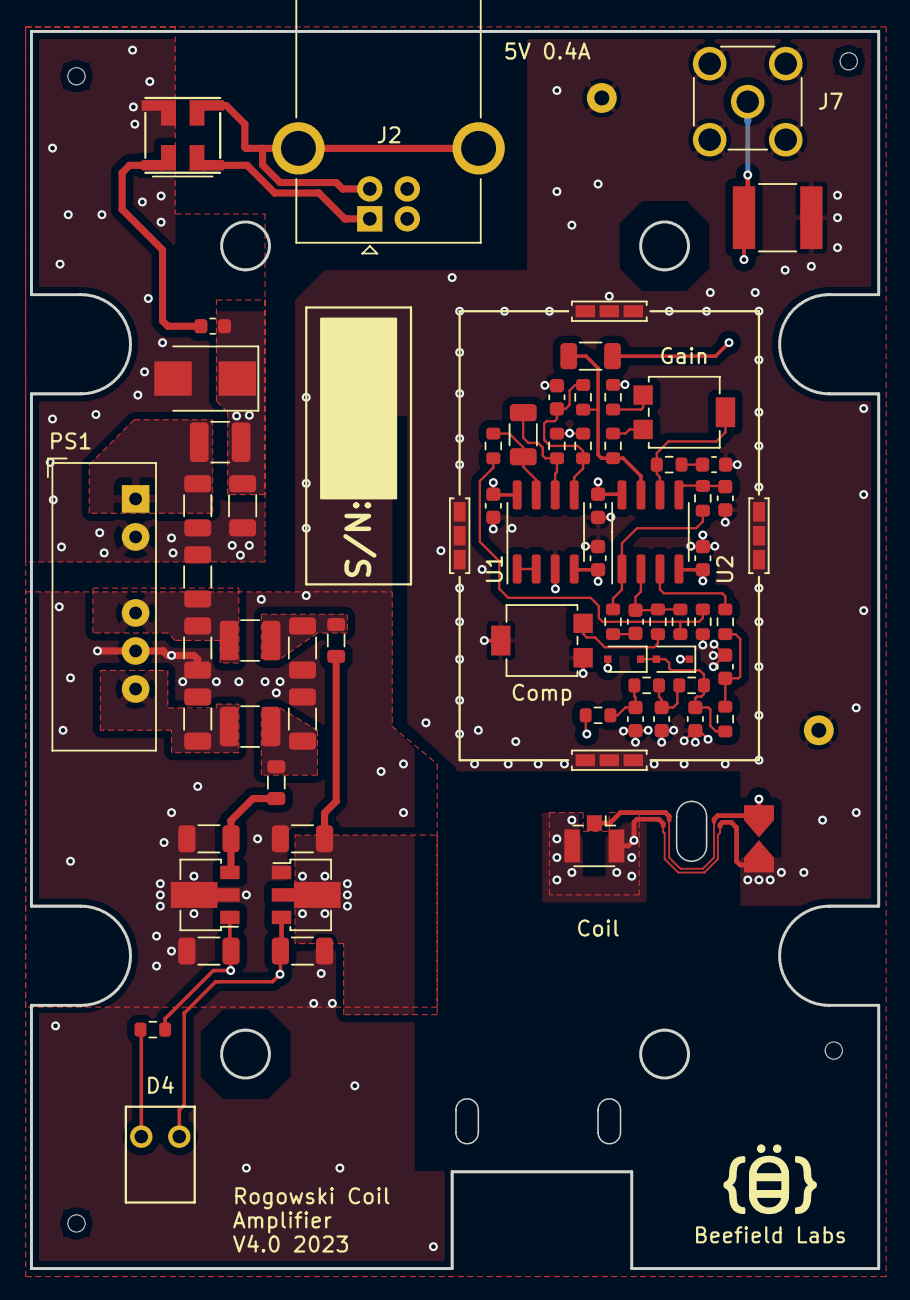
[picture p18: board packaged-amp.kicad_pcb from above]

Board: 4 copper layers, 56.6 x 82.7 mm, 77 parts (0 on the bottom side), 38 nets.

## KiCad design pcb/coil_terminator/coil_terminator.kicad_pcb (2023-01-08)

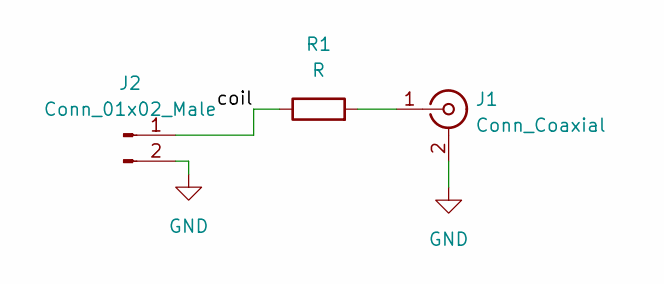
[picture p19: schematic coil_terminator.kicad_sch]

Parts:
J1: Conn_Coaxial; U.FL_Hirose_U.FL-R-SMT-1_Vertical
J2: Conn_01x02_Male; PinHeader_1x02_P1.27mm_Vertical
R1: R; R_1206_3216Metric_Pad1.30x1.75mm_HandSolder

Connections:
/coil: J2.1, R1.1
GND: J1.2 (Ext), J2.2
unnamed: J1.1 (In), R1.2

Board: 2 copper layers, 3 parts (0 on the bottom side), 3 nets, no tracks yet.

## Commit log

2022-10-09 inial project files
    [packaged-amp.kicad_pcb, packaged-amp.kicad_sch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]
2022-10-10 finished design of packaged amp
    [packaged-amp-B_Cu.gbr, packaged-amp-B_Mask.gbr, packaged-amp-B_Paste.gbr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]
2022-10-15 design sent to fab
    [packaged-amp-B_Cu.gbr, packaged-amp-B_Mask.gbr, packaged-amp-B_Paste.gbr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]
2022-11-11 next design revision
    [packaged-amp-B_Cu.gbr, packaged-amp-B_Mask.gbr, packaged-amp-B_Paste.gbr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]
2022-11-13 design revision
    [coil_terminator.kicad_pcb, coil_terminator.kicad_sch, packaged-amp.kicad_pcb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]
2022-11-13 updated panels
    [packaged-amp-panel-b-B_Cu.gbr, packaged-amp-panel-b-B_Mask.gbr, packaged-amp-panel-b-B_Paste.gbr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]
2022-11-14 pcb sent to production
    [packaged-amp-B_Cu.gbr, packaged-amp-B_Mask.gbr, packaged-amp-B_Paste.gbr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]
2022-12-16 added models for compensating coil loss
    [amplifier_measured.csv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]
2023-01-08 next revision
    [coil_terminator-B_Cu.gbr, coil_terminator-B_Mask.gbr, coil_terminator-B_Paste.gbr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]
2023-06-20 first public release
    [Digikey_BOM.csv, JLC_BOM.csv, amplifier_measured.csv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]

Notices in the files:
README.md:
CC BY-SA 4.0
